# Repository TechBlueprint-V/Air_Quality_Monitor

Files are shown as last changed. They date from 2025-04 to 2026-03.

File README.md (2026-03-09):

# Air_Quality_Monitor

This is an open-source, modular air quality monitoring system designed for both urban and remote deployments. It uses a combination of ESP32 and STM32 microcontrollers to collect and process real-time environmental data from various sensors measuring PM2.5, PM10, CO₂, VOCs, O₃, SO₂, and NO₂. The system features LoRa communication for long-range data transmission, GPS for location tagging, and a solar panel and charger for long-term usage. The hardware is custom-designed and includes power management for battery operation, while the firmware is optimized for low-power performance. All PCB designs, firmware code, and 3D-printed enclosure files are provided in this repository.

# Block Diagram

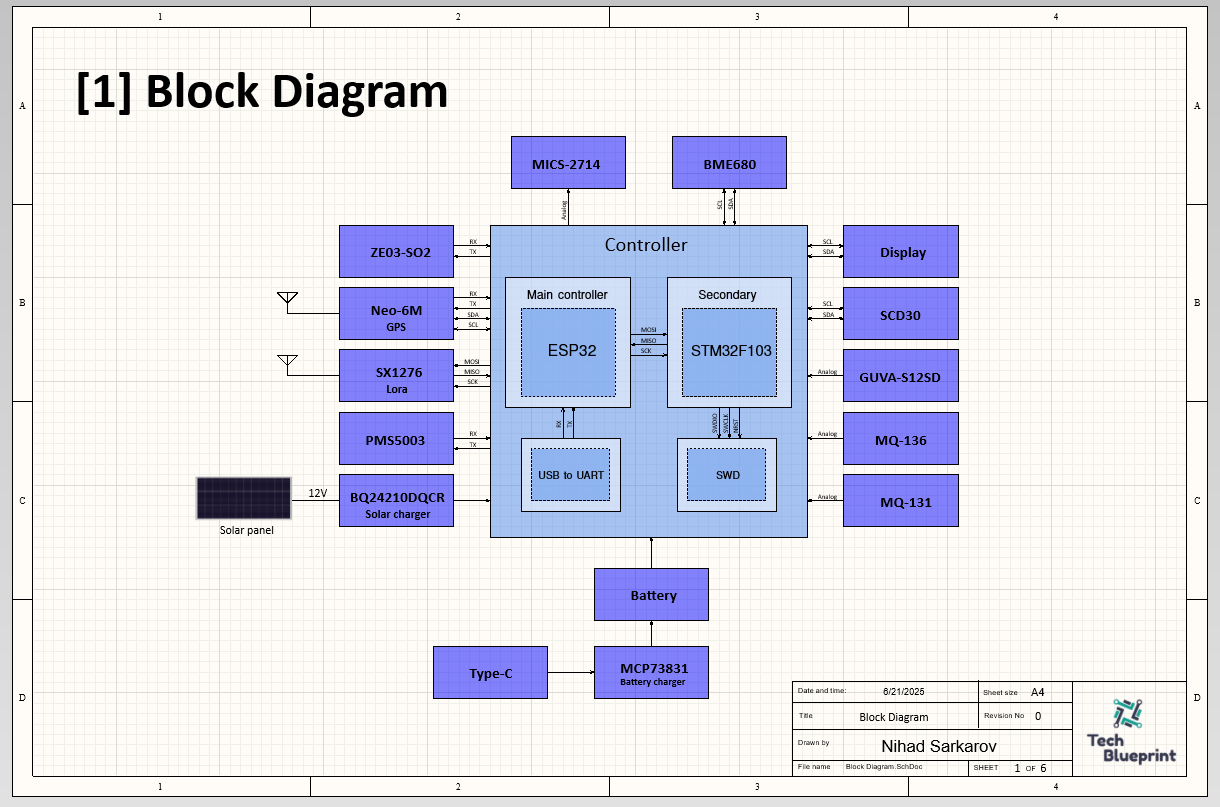
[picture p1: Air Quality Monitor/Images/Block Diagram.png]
Block Diagram


## Real View

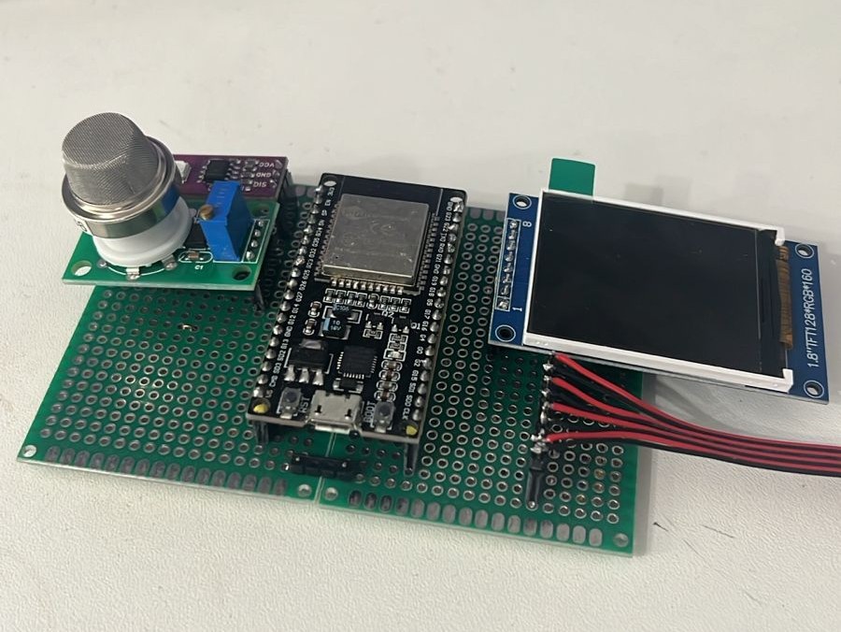
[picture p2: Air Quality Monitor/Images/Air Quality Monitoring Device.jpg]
Real View


*Note: The device shown above is an early prototype and not the final version. Development is still ongoing, and once the fully assembled version is complete, updated images and design details will be added here.* 

# Contents
- [Used Tools](#Used-Tools)
- [Features and Specifications](#Features-and-Specifications)
- [Schematic](#Schematic)
- [Layout](#Layout)
- [3D Views](#3D-Views)
- [Enclosure](#Enclosure)
- [Future Work](#Future-Work)
- [References](#References)

## Used Tools

**Altium Designer**

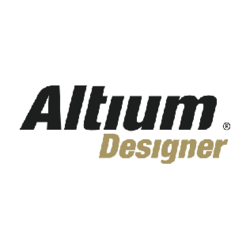
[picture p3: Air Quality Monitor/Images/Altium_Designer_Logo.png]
Altium Logo


   - Altium Designer (AD) is a software package for printed circuit board (PCB) design and electronic design automation. It is developed by the American software company Altium Limited. Altium Designer was formerly known under the brand Protel.

  **Saturn PCB Toolkit**

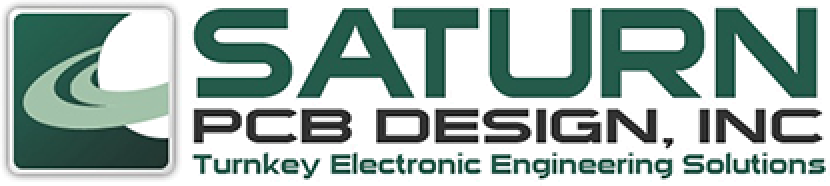
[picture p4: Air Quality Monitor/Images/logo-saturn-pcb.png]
Saturn PCB Toolkit Logo


  - The Saturn PCB Toolkit is the best freeware resource for PCB-related calculations. It incorporates many features that PCB designers and engineers regularly need, like the current capacity of a PCB trace, via current, differential pairs, and much more.

  **SolidWorks**

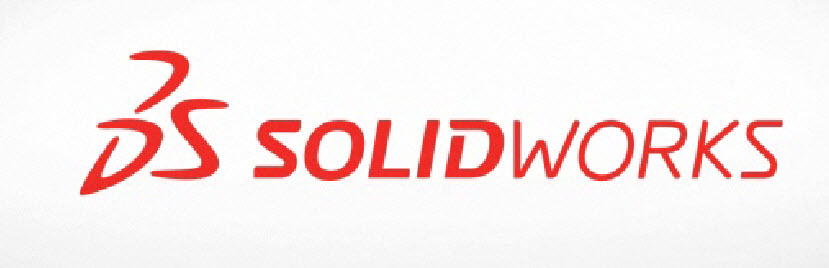
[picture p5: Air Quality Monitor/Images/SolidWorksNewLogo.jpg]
SolidWorks Logo


  - SolidWorks (stylized as SOLIDWORKS ) is a computer-aided 3D solid modeling and design (3D CAD) software. SolidWorks Corporation was founded in 1993 by Jon Hirschtick in Concord, Massachusetts. It was acquired by Dassault Systèmes in 1997 after releasing the first version of the software in 1995. It was the first 3D solid modeling (3D CAD) software integrated into Windows.

## Features and Specifications

| Feature | Description |
|---|---|
| Microcontrollers | ESP32 and STM32F103C8T6 (dual MCU architecture for efficient task handling)|
| Particulate Matter Sensor | PMS5003 - Measures PM2.5 and PM10 |
| Gas Sensors | MQ-136 (SO₂), MQ-131 (O₃), MICS-2714 (NO₂), BME680 (VOC) |
| CO₂ Sensor | SCD30 - Measures CO₂, humidity, and temperature |
| UV Sensor | GUVA-S12SD - Detects UV light intensity |
| Environmental Sensor | BME680 - Measures temperature, pressure, humidity, VOC |
| Communication | LoRa SX1276 - 868 MHz long-range wireless data transmission |
| GPS Module | NEO-6M - Provides geolocation tagging |
| Display | 1.54-inch TFT LCD - Displays live sensor readings |
| Power Supply | 1100mAh Li-ion Battery + USB-C charging |
| Power Management | MCP73831, MP2182GTL-Z, MIC2250, BQ24210 for voltage regulation and charging |
| Enclosure | 3D-printed custom case for outdoor use |
| Use Case Examples | Urban pollution monitoring, smart agriculture, remote environmental sensing |

## Schematic

**MCU**

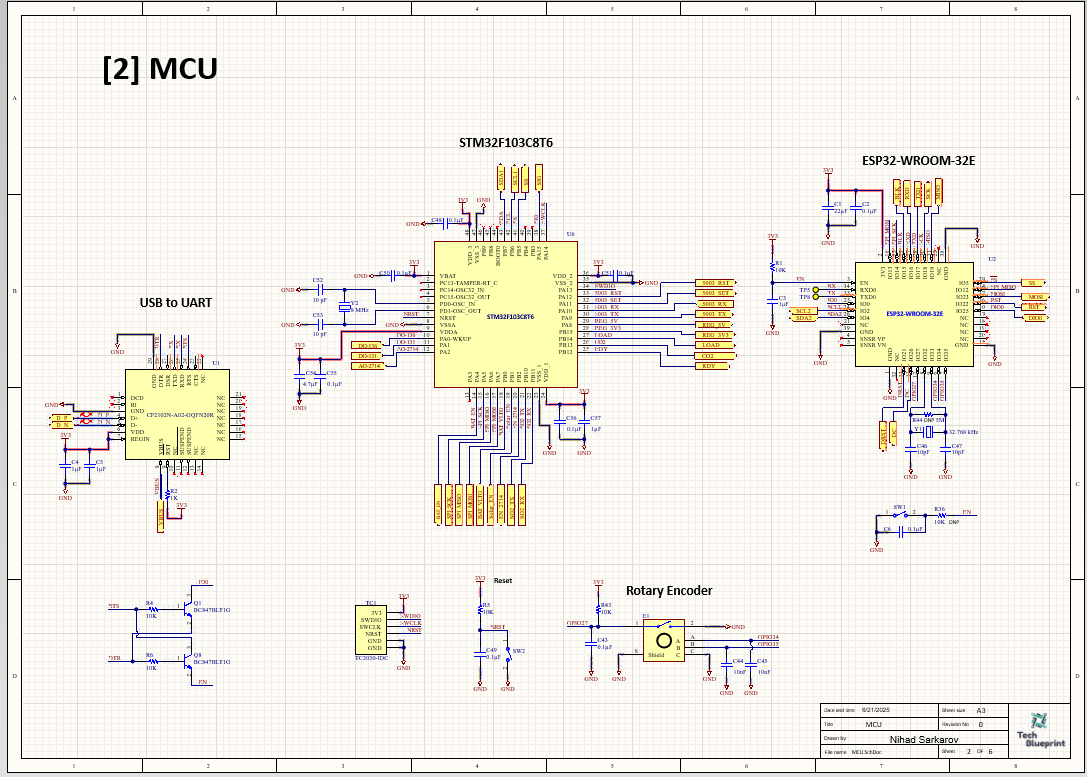
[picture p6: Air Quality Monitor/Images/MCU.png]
MCU


**Sensors**

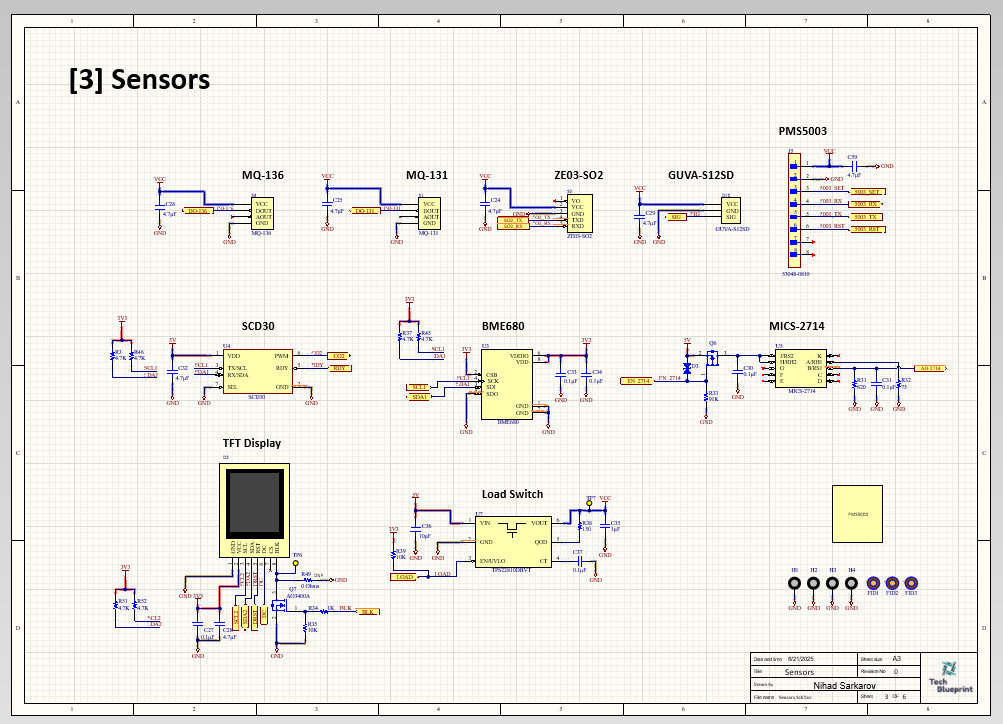
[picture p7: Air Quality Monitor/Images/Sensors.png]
Sensors


**Lora**

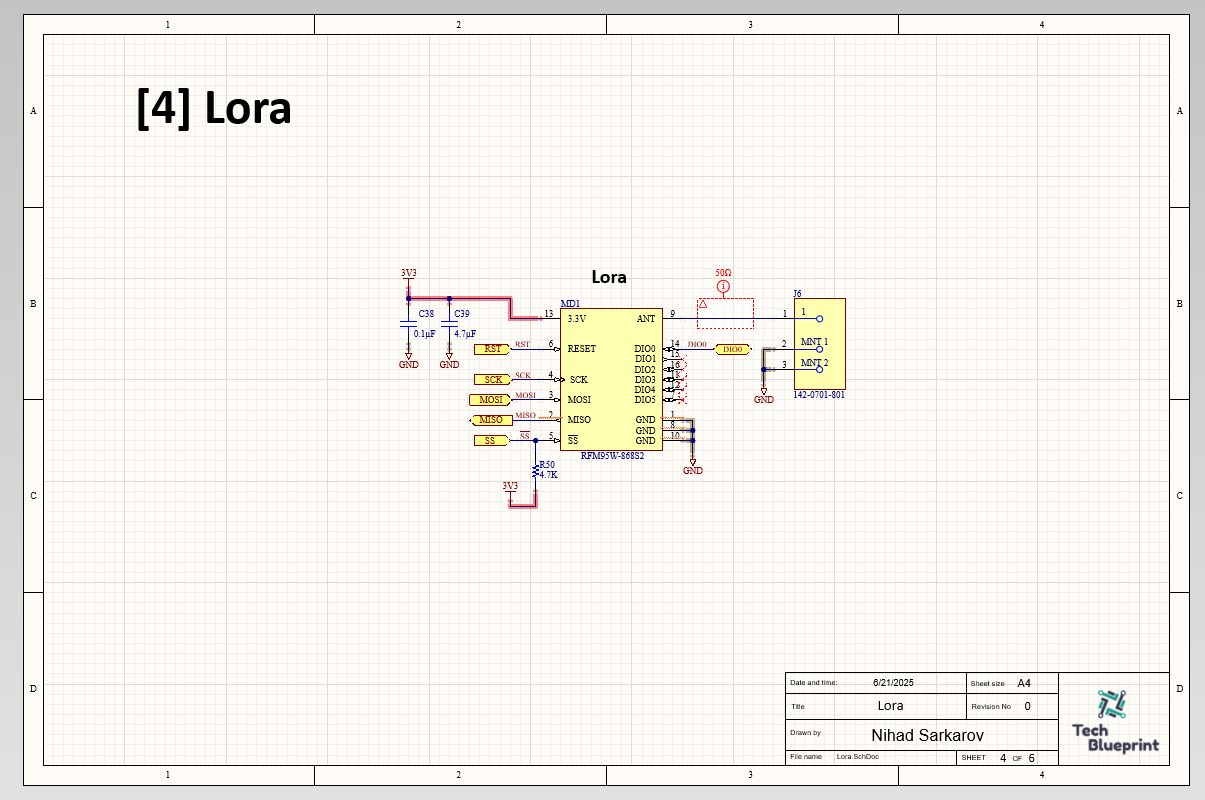
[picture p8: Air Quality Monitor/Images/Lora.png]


**GPS**

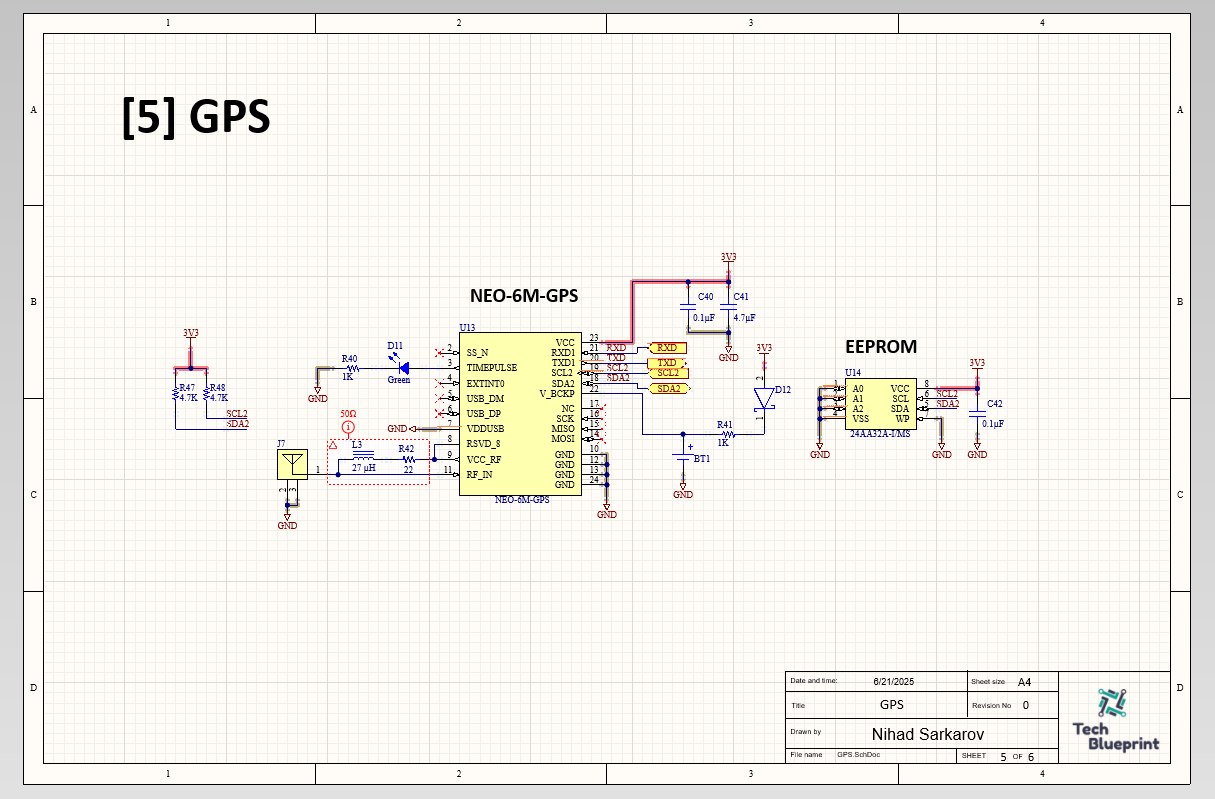
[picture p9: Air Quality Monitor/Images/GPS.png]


**Power**

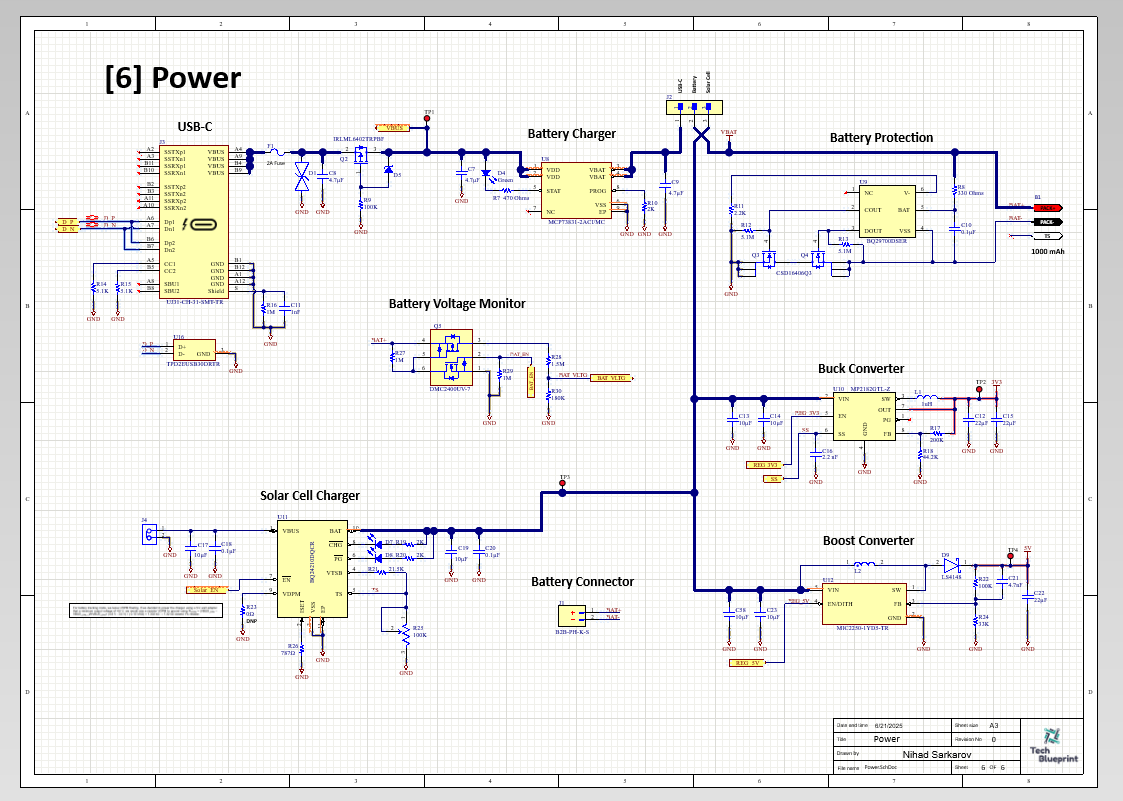
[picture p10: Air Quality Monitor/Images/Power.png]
Power


## Layout

**Layer-1**

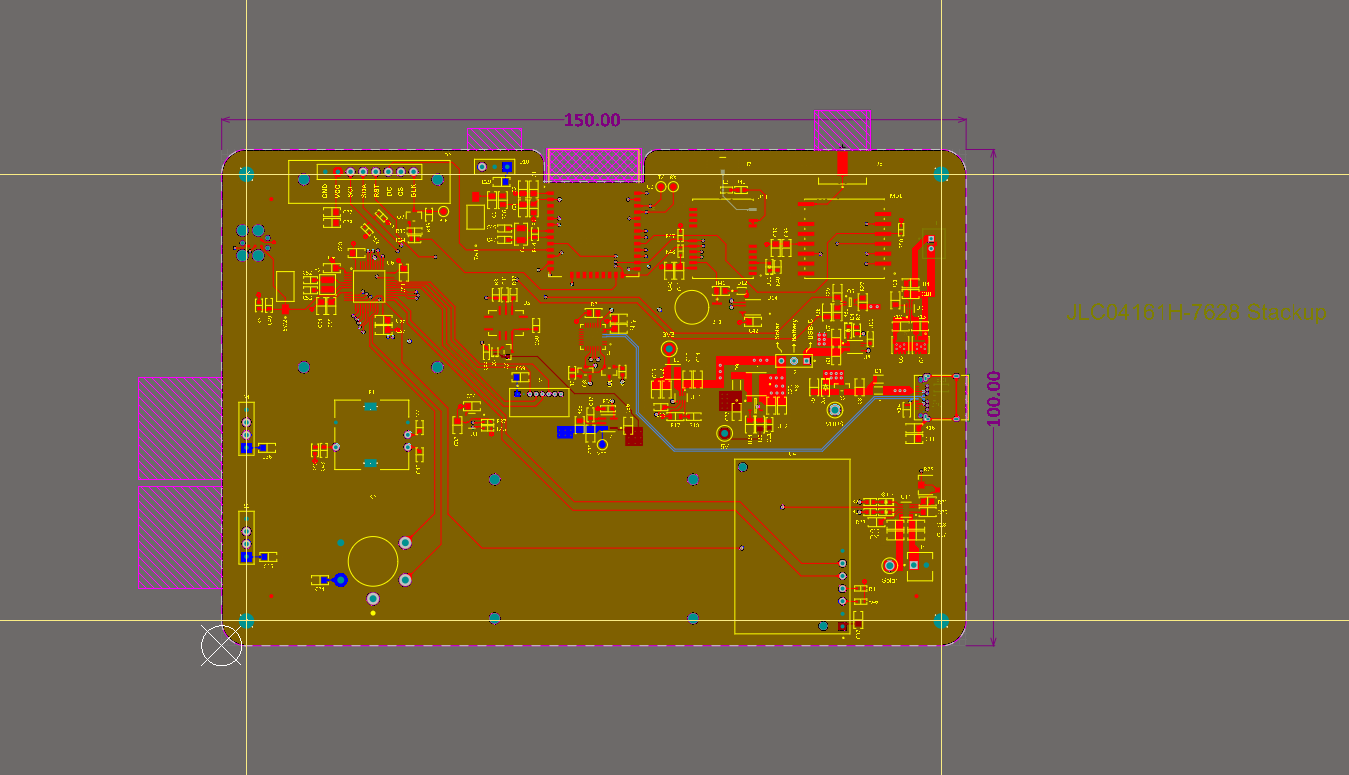
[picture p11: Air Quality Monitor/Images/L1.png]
Layer-1


**Layer-2**

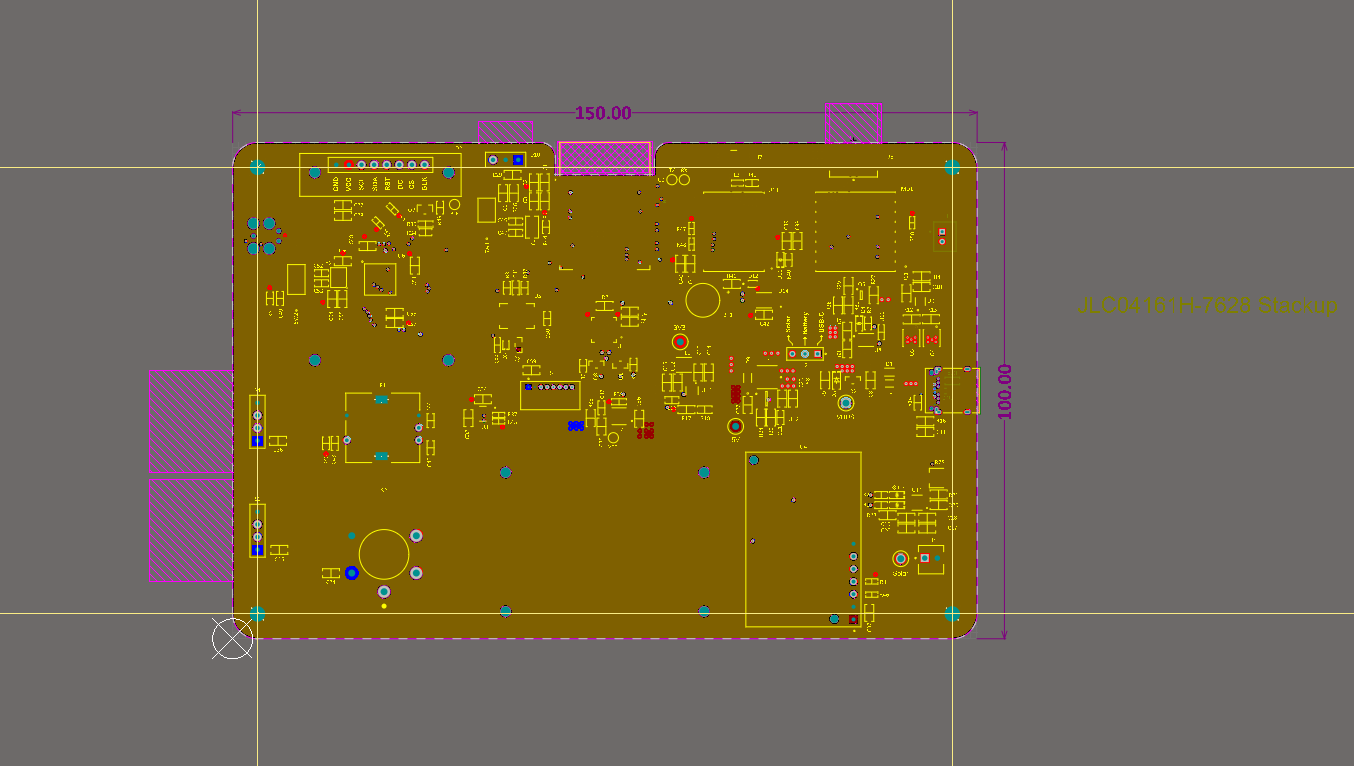
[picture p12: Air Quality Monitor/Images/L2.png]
Layer-2


**Layer-3**

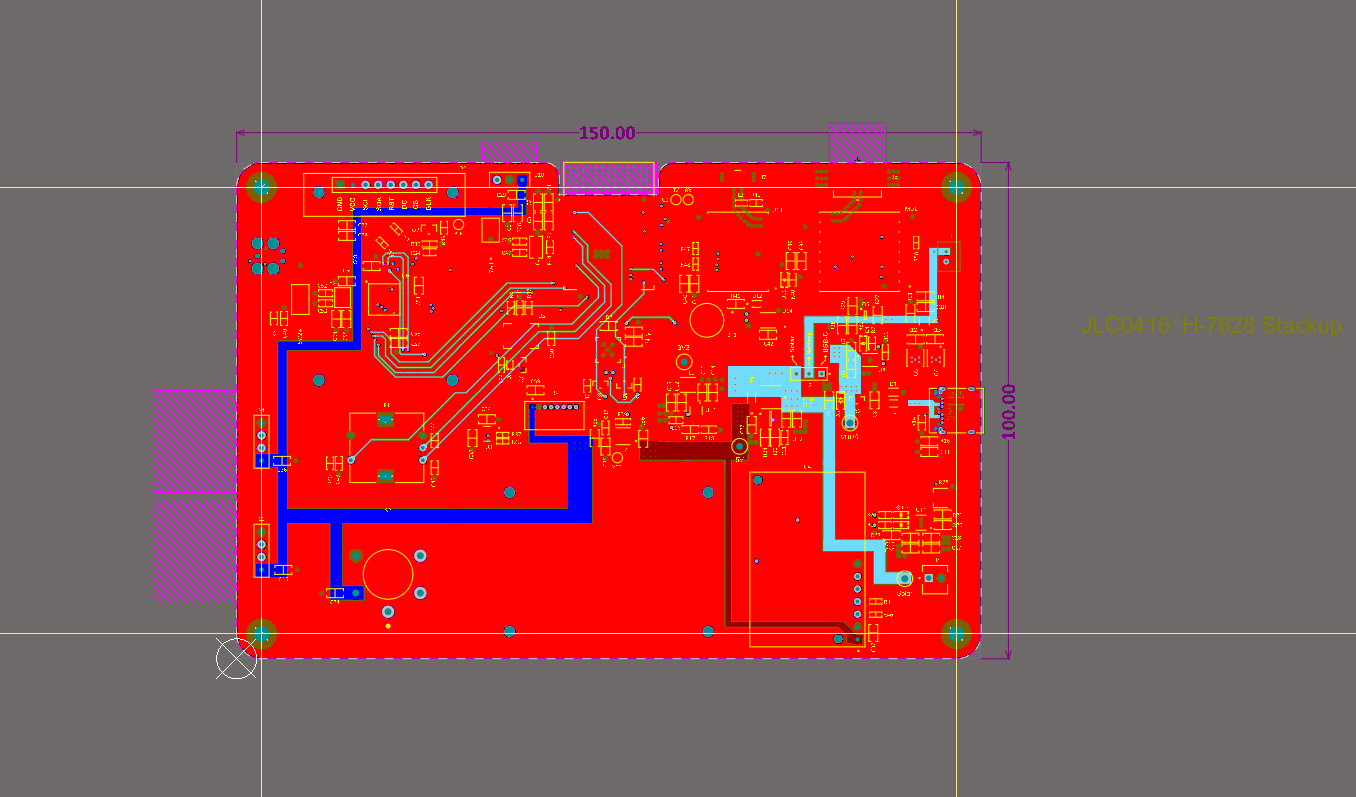
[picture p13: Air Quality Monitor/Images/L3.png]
Layer-3


**Layer-4**

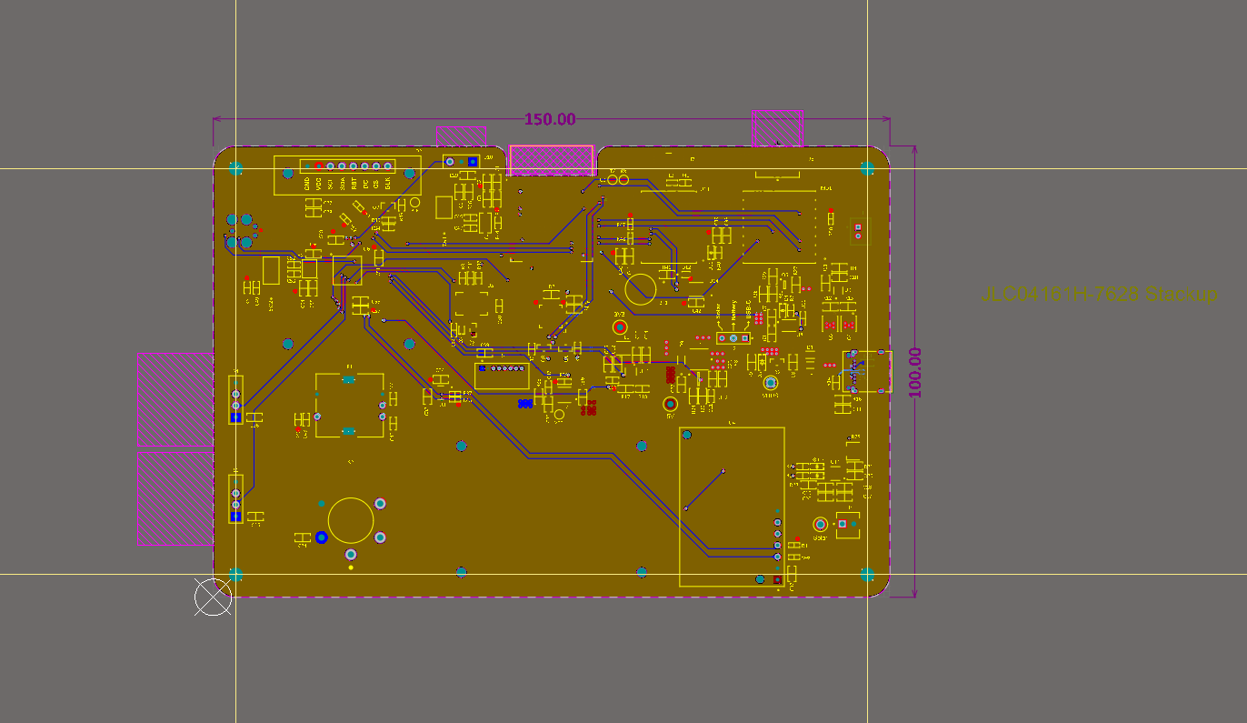
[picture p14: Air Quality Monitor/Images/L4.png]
Layer-4


## 3D Views

**3D-Top**

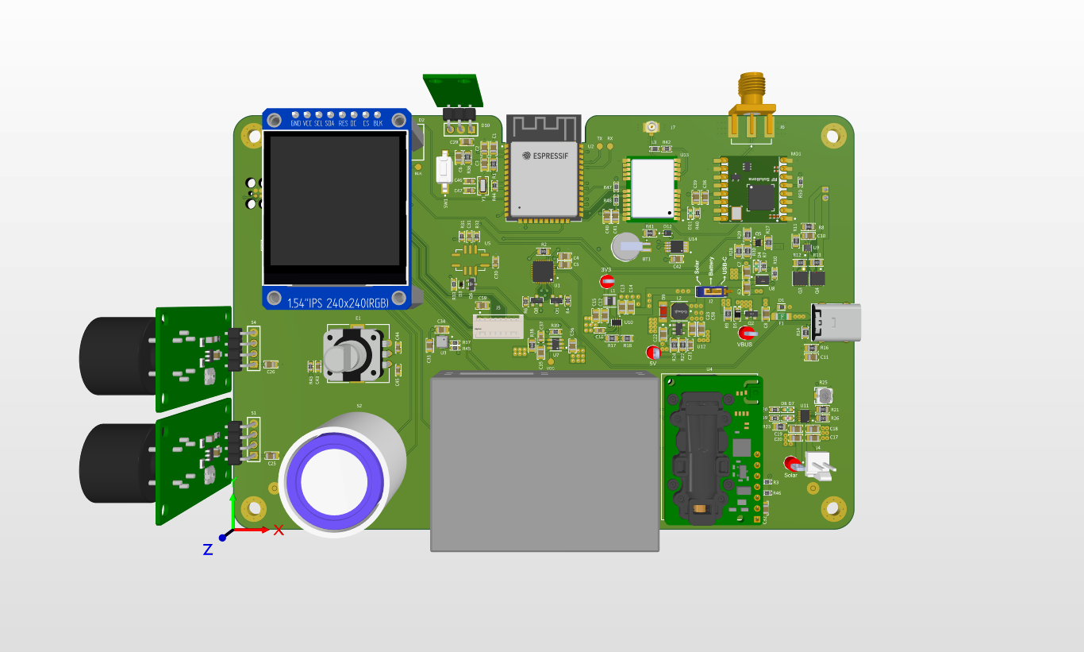
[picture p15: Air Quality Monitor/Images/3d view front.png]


**3D-Bottom**

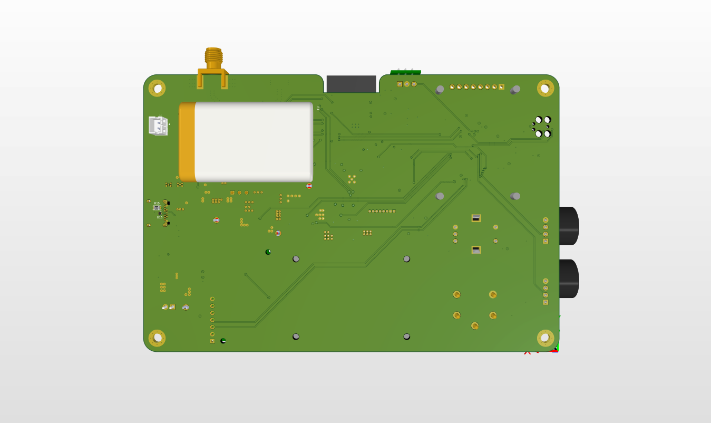
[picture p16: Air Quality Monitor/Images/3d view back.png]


**3D-Profile**

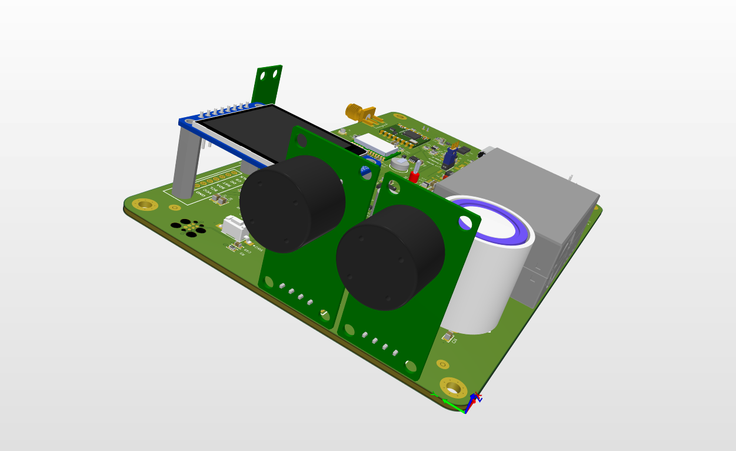
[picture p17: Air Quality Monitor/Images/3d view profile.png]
3D Profile


## Enclosure

**Enclosure view 1**

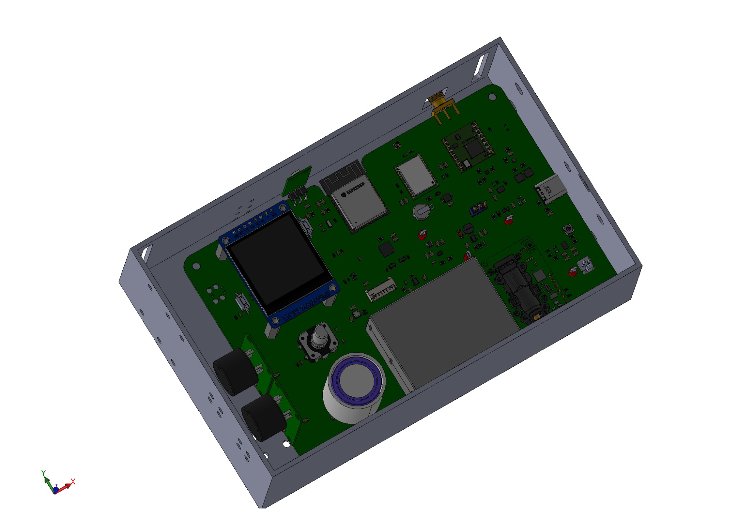
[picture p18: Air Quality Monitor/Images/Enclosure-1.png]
Enclosure-1


**Enclosure view 2**

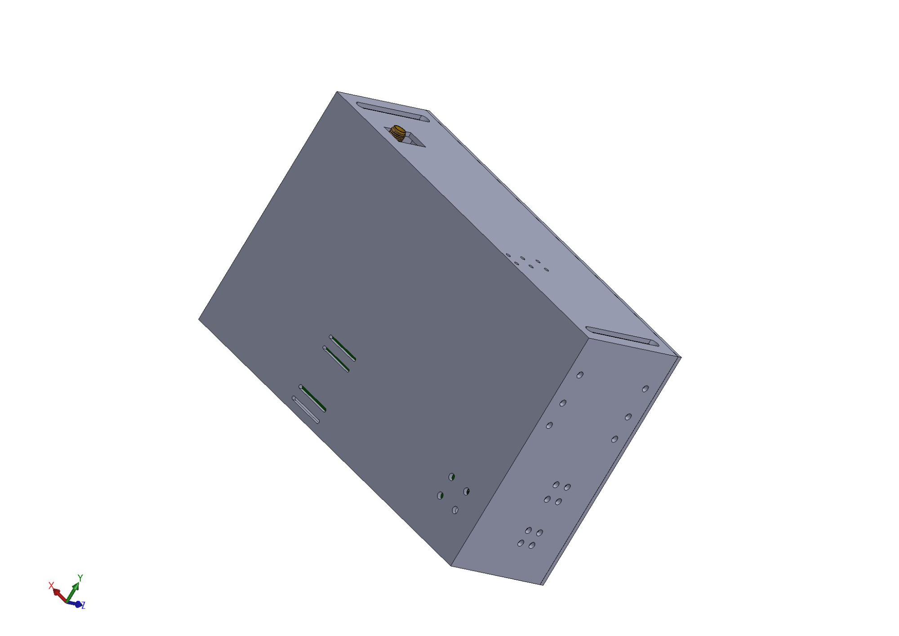
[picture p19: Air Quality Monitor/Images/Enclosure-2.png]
Enclosure-2


**Enclosure view 3**

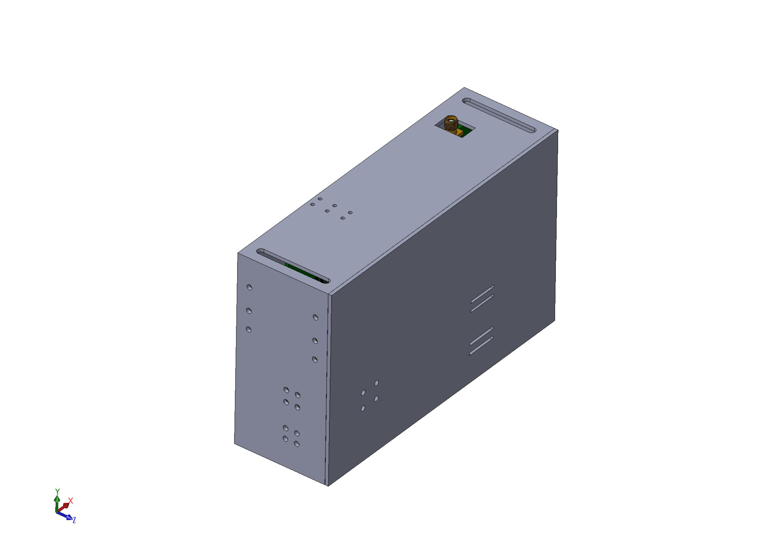
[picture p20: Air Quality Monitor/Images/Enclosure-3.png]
Enclosure-3


**Enclosure view 4**

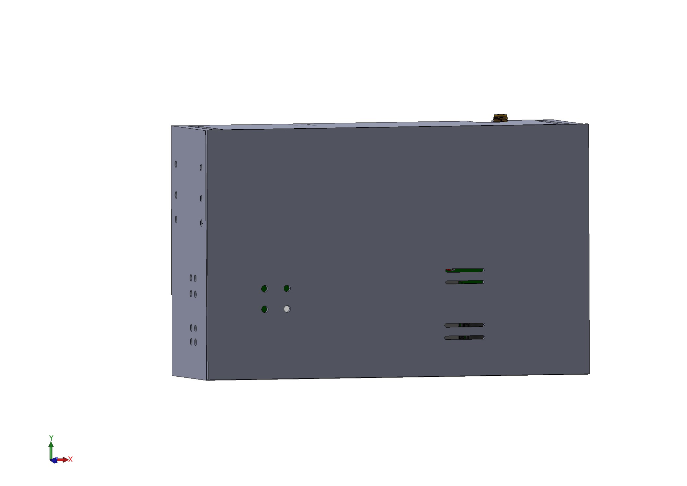
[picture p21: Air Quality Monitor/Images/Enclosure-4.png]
Enclosure-4


**Enclosure view 5**

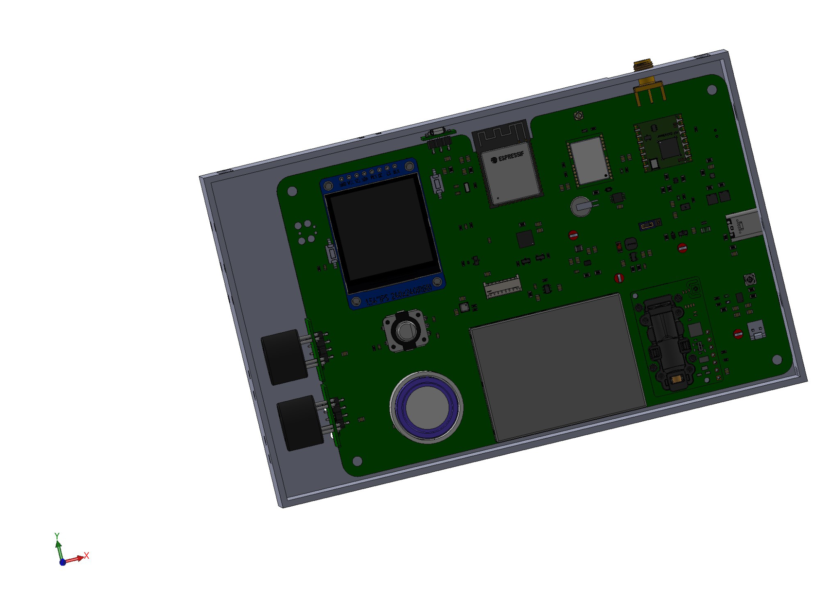
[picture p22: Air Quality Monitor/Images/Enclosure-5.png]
Enclosure-5


## Future Works

- **Cloud Integration and Dashboard**: Develop a cloud-based data logging and visualization dashboard to store historical air quality data and present trends using interactive charts and maps.
- **Mobile Application**: Create a companion Android/iOS app for real-time monitoring, GPS-based pollution alerts, and historical data access.
- **OTA (Over-the-Air) Firmware Updates**: Implement OTA functionality for ESP32 to allow remote firmware upgrades without physical access.
- **Machine Learning for Pollution Prediction**: Integrate lightweight ML models to analyze collected data and predict air quality trends based on environmental factors.
- **Solar Power Option**: Design and test a solar-powered charging module to support long-term outdoor deployment without manual charging.
- **Additional Sensors**: Expand sensor support for detecting carbon monoxide (CO), lead (Pb), or other industrial pollutants.
- **LoRaWAN Gateway Support**: Enable compatibility with public or private LoRaWAN gateways to support broader communication networks.

## Contributors

- **Nihad Sarkarov** – Hardware architecture, PCB design, component selection -   [LinkedIn](https://www.linkedin.com/in/nihad-sarkarov-35b959232/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)

- **Farid Murshudlu** – Firmware development, application UI design -  [LinkedIn](https://www.linkedin.com/in/farid-murshudlu/)
 
- **Ali Askerov** – Mechanical design, enclosure design -  [LinkedIn](https://www.linkedin.com/in/ali-askarov-596a0b258/)
  
## References

1. Plantower PMS5003 Datasheet – [https://files.particle.io](https://www.aqmd.gov/docs/default-source/aq-spec/resources-page/plantower-pms5003-manual_v2-3.pdf)
2. Sensirion SCD30 CO2 Sensor Datasheet – [https://www.sensirion.com](https://sensirion.com/media/documents/4EAF6AF8/61652C3C/Sensirion_CO2_Sensors_SCD30_Datasheet.pdf)
3. Bosch BME680 Sensor Datasheet – [https://www.bosch-sensortec.com](https://www.bosch-sensortec.com/media/boschsensortec/downloads/datasheets/bst-bme680-ds001.pdf)
4. MQ Sensor Series Overview – [https://www.winsen-sensor.com](https://www.pololu.com/file/0j309/mq2.pdf)
5. NEO-6M GPS Module Datasheet – [https://cdn.sparkfun.com](https://content.u-blox.com/sites/default/files/products/documents/NEO-6_DataSheet_%28GPS.G6-HW-09005%29.pdf)
6. Semtech SX1276 LoRa Transceiver Datasheet – [https://www.semtech.com](https://semtech.my.salesforce.com/sfc/p/E0000000JelG/a/2R0000001Rbr/6EfVZUorrpoKFfvaF_Fkpgp5kzjiNyiAbqcpqh9qSjE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)
7. STM32F103C8T6 Reference Manual – [https://www.st.com]([https://www.st.com/resource/en/reference_manual/CD00171190.pdf](https://www.st.com/resource/en/reference_manual/rm0008-stm32f101xx-stm32f102xx-stm32f103xx-stm32f105xx-and-stm32f107xx-advanced-armbased-32bit-mcus-stmicroelectronic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))
8. ESP32 Technical Reference Manual – [https://www.espressif.com](https://www.espressif.com/sites/default/files/documentation/esp32_technical_reference_manual_en.pdf)
9. [PlatformIO](https://platformio.org/) – Cross-platform development environment
10. [STM32CubeIDE](https://www.st.com/en/development-tools/stm32cubeide.html) – Integrated development tool for STM32 microcontrollers

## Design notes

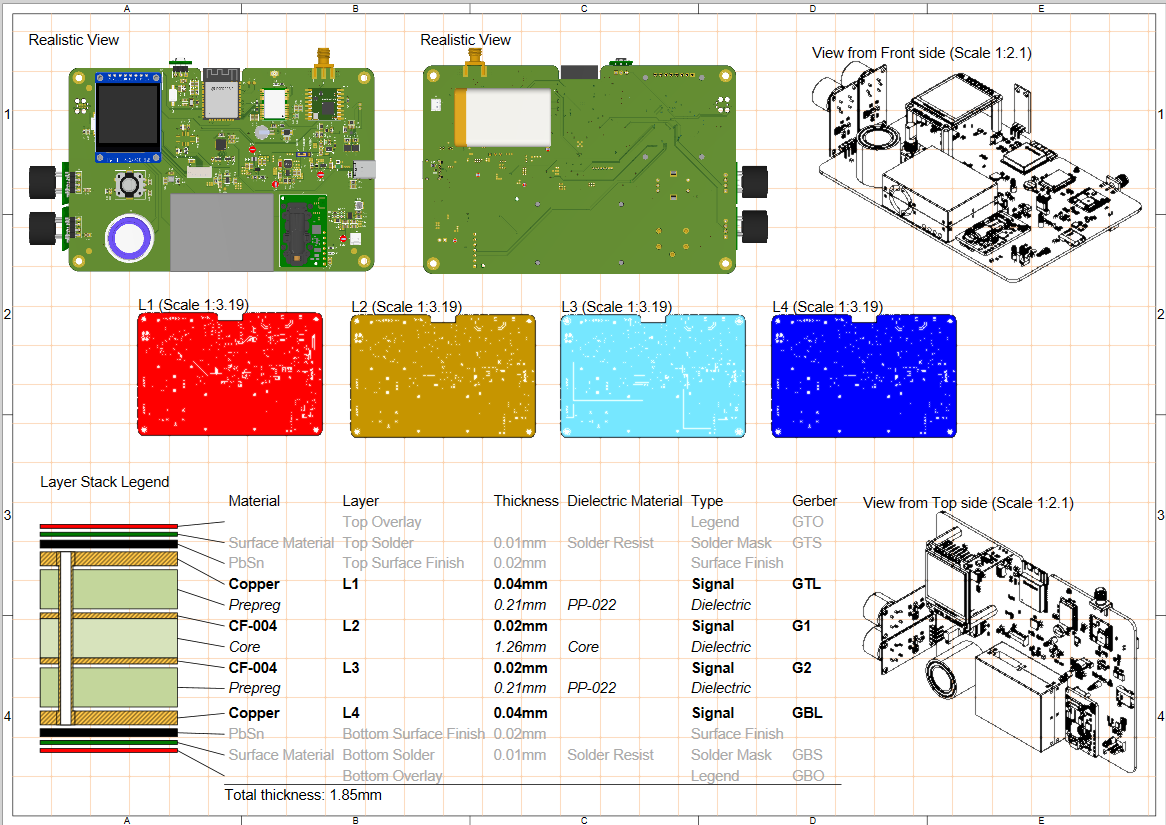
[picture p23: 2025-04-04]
Air Quality Monitor/Hardware Design Files/Altium/Draftsman/Draftsman.png

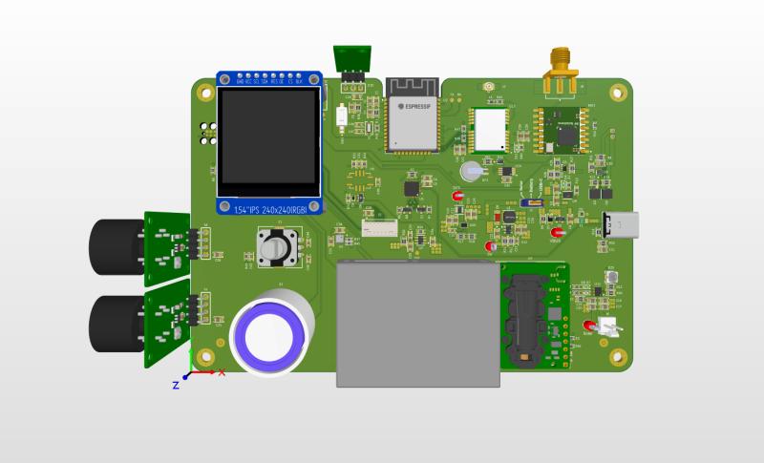
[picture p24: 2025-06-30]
Air Quality Monitor/Images/3D Top.jpeg

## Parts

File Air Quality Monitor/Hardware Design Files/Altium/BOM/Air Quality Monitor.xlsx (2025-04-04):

Comment | Description | Designator | Footprint | LibRef | Quantity
Battery | 1000 mAh | B1 | 1000 mAh battery | Battery | 1
MS621FE-FL11E |  | BT1 | BAT_MS621FE-FL11E | MS621FE-FL11E | 1
22µF | CAP CER 22UF 6.3V X5R 0805 | C1, C12, C15, C22 | CAP 0805_2012 | 08056D226KAT2A | 4
0.1µF | CAP CER 0.1UF 25V X7R 0805 | C2, C6, C10, C18, C20, C27, C33, C34, C38, C40, C42, C48, C50, C51, C55, C56 | CAP 0805_2012 | 08053C104KAT4A, 08053C104K4Z2A | 16
1µF | CAP CER 1UF 6.3V X5R 0805, CAP CER 1UF 10V X7R 0805 | C3, C4, C5, C35, C57 | CAP 0805_2012 | LGC26D105MAT2S1, MM05ZC105KCZ2A | 5
4.7µF | CAP CER 4.7UF 10V X5R 0805 | C7, C8, C9, C24, C25, C26, C28, C29, C32, C39, C41, C54, C59 | CAP 0805_2012 | 0805ZD475KAT2A | 13
1000 pF | CAP CER 0805 1NF 250V C0G 1% | C11 | CAP 0805_2012 | C0805C102FAGECAUTO | 1
10µF | CAP CER 10UF 10V X5R 0805 | C13, C14, C17, C19, C23, C36, C58 | CAP 0805_2012 | 0805ZD106KAT4A | 7
2200 pF | CAP CER 0603 2.2NF 16V X7R 10% | C16 | CAP 0603_1608 | C0603C222K4RECAUTO | 1
4700 pF | CAP CER 0603 4.7NF 16V X7R 10% | C21 | CAP 0603_1608 | C0603C472K4RECAUTO | 1
0.1µF | CAP CER 0.1UF 16V X7R 0603, CAP CER 0.1UF 25V X7R 0603 | C30, C31, C37, C43, C49 | CAP 0603_1608 | 0603YC104KAT4A, 06033C104K4T4A | 5
10000 pF | CAP CER 0603 10NF 16V X7R 10% | C44, C45 | CAP 0603_1608 | C0603C103K4RECAUTO | 2
10pF | CAP CER 10PF 50V NP0 0603 | C46, C47 | CAP 0603_1608 | 06035A100J4T2A | 2
10 pF | CAP CER 10PF 50V C0G/NP0 0603 | C52, C53 | CAP 0603_1608 | 500X14N100MV4T | 2
EZA-EG3A50AV | EZA-EG3A50AV EZAEG Series 100 Vcl 0.1 pF 0603 Surface Mount ESD Suppressor | D1 | FP-EZAEG3A-MFG | CMP-00287-39618349-1 | 1
1.54 Inch TFT | 1.54 inch TFT Display 1.54" LCD Screen Module 240*240 240x240 SPI interface ST7789 Driver Board | D2 | 1.54 Inch Display | Display | 1
RCLAMP2261PW.C | 22V ESD & EOS PROTECTION | D3 | 0402 | RCLAMP2261PW.C | 1
Green | LED GREEN CLEAR CHIP 0603 SMD | D4, D8, D11 | LED 0603_1608 GREEN | LSM0603453V | 3
PZU3.0B2A,115 | DIODE ZENER 3V 320MW SOD323 | D5 | SOD323 | PZU3.0B2A,115 | 1
Red | 0603 LED RED 620NM DOMINANT,630N | D7 | LED 0603_1608 RED | QBLP601-R5-2897 | 1
LS4148 | DIODE GEN PURP 75V 150MA SOD80 | D9 | FP-6_560-5006_01-4-MFG | CMP-02539-000014-1 | 1
GUVA-S12SD | Photodiode 2-SMD, J-Lead | D10 | GUVA-S12SD | GUVA-S12SD | 1
B0530WS-7-F | DIODE SCHOTTKY 30V 500MA SOD323 | D12 | FP-SOD323-MFG | CMP-12790-000023-1 | 1
PEC11R-4315F-S0012 | ROTARY ENCODER MECHANICAL 12PPR | E1 | BOURNS PEC11R-4315F-S0012 | PEC11R-4315F-S0012 | 1
3413.0219.22 | FUSE BRD MNT 2A 32VAC 63VDC 1206 | F1 | FUSE 1206_3216 0.6MM | 3413.0219.22 | 1
Mounting Hole |  | H1, H2, H3, H4 | Mounting Hole | Mounting Hole | 4
B2B-PH-K-S |  | J1 | JST_B2B-PH-K-S | B2B-PH-K-S | 1
87224-3 | CONN HEADER VERT 3POS 2.54MM | J2 | FP-87224-3-MFG | CMP-2000-05697-2 | 1
UJ31-CH-31-SMT-TR | CONN RCPT USB3.1 TYPEC 24POS R/A | J3 | CUI UJ31-CH-31-SMT-TR | UJ31-CH-31-SMT-TR | 1
640456-2 | Male Header, Pitch 2.54 mm, 1 x 2 Position, Height 10.49 mm, Tail Length 3.556 mm, -55 to 105 degC, RoHS, Bulk | J4 | TECO-640456-2_V | CMP-2000-05417-1 | 1
53048-0810 | CONN HEADER R/A 8POS 1.25MM | J5 | FP-530480810-MFG | CMP-04776-000035-2 | 1
142-0701-801 | CONN SMA JACK STR 50OHM EDGE MNT | J6 | FP-142-0701-801-MFG | CMP-09588-000002-1 | 1
U.FL-R-SMT-1(10) | CONN U.FL RCPT STR 50 OHM SMD | J7 | FP-U_FL-R-SMT-1_10-MFG | CMP-2000-05152-3 | 1
1239AS-H-1R0M=P2 | Shielded Wirewound Inductor 1uH 20% 3000mA 0.059Ω 1008 (2520) | L1 | FP-DFE252012C-IPC_C | CMP-06042-014115-1 | 1
LPS4018-104MRB | INDUCTOR, SHLD, 100UH, 20%, 0.35A, SMD | L2 | FP-LPS4018-MFG | CMP-11268-000169-1 | 1
27 µH | FIXED IND 27UH 2MA 1.8 OHM SMD | L3 | TDK MLF1608 | MLF1608C270KTD00 | 1
RFM95W-868S2 | RX TXRX MODULE ISM < 1GHZ SMD | MD1 | FP-RFM95W-868S2-MFG | CMP-204316-000001-1 | 1
BC847BLT1G |  | Q1, Q8 | ON_Semi_318-08_MFG | CMP-1048-00759-2 | 2
IRLML6402TRPBF | MOSFET P-CH 20V 3.7A SOT-23 | Q2 | FP-Micro3-MFG | CMP-32901-000130-1 | 1
CSD16406Q3 | MOSFET N-CH 25V 60A 8-SON | Q3, Q4 | FP-DQG0008A-MFG | CMP-04962-000044-1 | 2
DMC2400UV-7 | Complementary Pair Enhancement Mode MOSFET, 20 V N-Channel, -20 V P-Channel, -55 to 150 degC, 6-Pin SOTFL (SOT563), RoHS, Tape and Reel | Q5 | DIOD-SOT563-6_V | CMP-2000-06168-1 | 1
SI2301BDS-T1-GE3 | SI2301BDS-T1-GE3 Trans Mosfet P-ch Si 20V 2.2A 3-PIN SOT-23 T/r / Mosfet P-ch 20V 2.2A SOT23-3 | Q6 | FP-S-03946-MFG | CMP-00030-42864886-1 | 1
AO3400A | MOSFET N-CH 30V 5.7A SOT23 | Q7 | FP-SOT23-MFG | CMP-83955-000006-1 | 1
10K | RES SMD 10K OHM 5% 1/3W 0805 | R1, R36 | RES 0805_2012 | CRGH0805J10K | 2
1K | RES SMD 1K OHM 5% 1/3W 0805 | R2, R41 | RES 0805_2012 | CRGH0805J1K0 | 2
4.7K | RES 4.7K OHM 5% 1/10W 0603 | R3, R37, R45, R46, R47, R48, R50, R51, R52 | KOA RES RK73 RN73 0603_1608 | RK73B1JTTD472J | 9
10K | RES SMD 10K OHM 5% 1/10W 0603 | R4, R5, R6, R43 | RES 0603_1608 | CRCW060310K0JNEA | 4
470 Ohms | RES 470 OHM 5% 1/10W 0603 | R7 | RES 0603_1608 | RMCF0603JT470R | 1
330 Ohms | RES 330 OHM 5% 1/8W 0805 | R8 | RES 0805_2012 | CRCW0805330RJNEAC | 1
100K | RES 100K OHM 1% 1/3W 0805 | R9, R22 | RES 0805_2012 | CRGP0805F100K | 2
2K | RES 2K OHM 1% 1/10W 0603 | R10 | YAGEO RES 0603_1608 | RC0603FR-072KP | 1
2.2K | RCC0805 100 2K2 1% ET1 E3 | R11 | RES 0805_2012 | RCC08052K20FKEA | 1
5.1M | RES SMD 5.1M OHM 5% 0.4W 0805 | R12, R13 | RES 0805_2012 | ESR10EZPJ515 | 2
5.1K | RES 5.1K OHM 5% 1/4W 0805 | R14, R15 | YAGEO RES RK73 RS73 SG73 0805_2012 | SG73S2ATTD512J | 2
1M | RES SMD 1M OHM 1% 1/2W 0805, RES SMD 1M OHM 5% 1/2W 0805 | R16, R27, R29 | RES 0805_2012 | RCS08051M00FKEA, CRCW08051M00JNEAHP | 3
200K | RES 200K OHM 1% 1/8W 0805 | R17 | YAGEO RES 0805_2012 | RC0805FR-07200KL | 1
44.2K | RES 44.2K OHM 1% 1/4W 0805 | R18 | YAGEO RES RK73 RS73 SG73 0805_2012 | RK73H2ATTD4422F | 1
2K | RES 2K OHM 5% 1/10W 0603 | R19, R20 | RES 0603_1608 | RMCF0603JT2K00 | 2
21.5K | RCG0805 100 21K5 1% EA | R21 | RES 0805_2012 | RCG080521K5FKEA | 1
0Ω | RES SMD 0 OHM 1% 1/8W 0805 | R23 | RES 0805_2012 | CRCW0805787RFKEA | 1
33K | RES 33K OHM 1% 1/3W 0805 | R24 | RES 0805_2012 | CRGP0805F33K | 1
TC33X-2-104E | TRIMMER 100K OHM 0.1W J LEAD TOP | R25 | FP-TC33X-2-MFG | CMP-07234-000040-1 | 1
787Ω | RES SMD 787 OHM 1% 1/8W 0805 | R26 | RES 0805_2012 | CRCW0805787RFKEA | 1
1.5M | RES 1.5M OHM 1% 1/8W 0805 | R28 | RES 0805_2012 | RMCF0805FT1M50 | 1
180K | RES 180K OHM 1% 1/3W 0805 | R30 | RES 0805_2012 | CRGP0805F180K | 1
820 | RES SMD 820 OHM 1% 1/10W 0603 | R31 | RES 0603_1608 | KTR03EZPF8200 | 1
75 | RES SMD 75 OHM 1% 1/10W 0603 | R32 | RES 0603_1608 | RCA060375R0FKEA | 1
91K | RES 91K OHM 5% 1/10W 0603 | R33 | YAGEO RES 0603_1608 | RC0603JR-0791KL | 1
1K | RES 1K OHM 5% 1/10W 0603 | R34, R40 | RES 0603_1608 | RMCF0603JT1K00 | 2
10K | RES SMD 10K OHM 5% 1/10W 0603 | R35, R39 | YAGEO RES 0603_1608 | AC0603JR-0710KL | 2
150 | RES 150 OHM 1% 1/3W 0805 | R38 | RES 0805_2012 | CRGP0805F150R | 1
22 | RES SMD 22 OHM 1% 1/10W 0603 | R42 | RES 0603_1608 | ERJ-3EKF22R0V | 1
5M | RES SMD 5M OHM 1% 1/10W 0603 | R44 | RES 0603_1608 | HVC0603T5004FET | 1
0 Ohms | RES 0 OHM JUMPER 0603 | R49 | RES 0603_1608 | TLRZ1JTTD | 1
MQ-131 | MQ-131 Sensor Module | S1 | MQ-131 Sensor Module | MQ-131 Module | 1
ZE03-SO2 | Portable and fixed gas detector, various gas detection equipment and situation. | S2 | ZE03-SO2 | ZE03-SO2 | 1
MQ-136 | They are used in air quality control equipments for buildings/offices, are suitable for detecting Of H2S | S4 | MQ-136 Sensor Module | MQ-136 Sensor Module | 1
FSMSMTR | FSMSM Push Button Switch, 50 mA, -35 to 85 degC, 2-Pin SMD, RoHS, Tape and Reel | SW1, SW2 | TECO-FSMSMTR_V | CMP-2000-07501-1 | 2
TC2030-IDC | PLUG-OF-NAILS 6-PIN W/ LEGS 8 | TC1 | TC2030-IDC | TC2030-IDC | 1
5010 | Test Point, Red, Through Hole, RoHS, Bulk | TP1, TP2, TP3, TP4 | KSTN-5010_V | CMP-1672-00002-4 | 4
Test point | 1mm x 1mm round pad for testing purposes | TP5, TP6, TP7, TP8 | Test point | Test point | 4
CP2102N-A02-GQFN20R | USB Bridge, USB to UART USB 2.0 UART Interface 20-QFN (3x3) | U1 | QFN50P500X500X100-29N | CP2102 | 1
ESP32-WROOM-32E(M113EH3200PH3Q0) | RX TXRX MOD WIFI TRACE ANT SMD | U2 | FP-ESP32-WROOM-32E_M113EH-MFG | CMP-194065-000012-1 | 1
BME680 |  | U3 | PSON80P300X300X100-8N | BME680 | 1
SCD30 | CO2 MODULE | U4 | FP-SCD30-MFG | CMP-144026-000005-1 | 1
MICS-2714 | Gas sensor for Nitrogen Dioxide | U5 | MICS-SMD10 | MICS-2714 | 1
STM32F103C8T6 | ARM® Cortex®-M3 STM32F1 Microcontroller IC 32-Bit 72MHz 64KB (64K x 8) FLASH 48-LQFP (7x7) | U6 | LQFP-48_19.6_393_58X11_SMD | IC_STM32F103C8T6 | 1
TPS22810DBVT | IC PWR SWITCH N-CHAN 1:1 SOT23-6 | U7 | FP-DBV0006A-IPC_A | CMP-04912-000018-2 | 1
MCP73831-2ACI/MC | IC CONTROLLER LI-ION 4.2V 8DFN | U8 | FP-C04-123-MFG | CMP-06318-000002-1 | 1
BQ29700DSER | IC LITHIUM BATT PROTECT 6-SON | U9 | FP-DSE0006A-IPC_A | CMP-04911-000043-1 | 1
MP2182GTL-Z | Buck Switching Regulator IC Positive Adjustable 0.6V 1 Output 2A SOT-583 | U10 | SOT583_MP2182_MNP | MP2182GTL-Z | 1
BQ24210DQCR |  | U11 | SON50P300X200X80-11N | BQ24210DQCR | 1
MIC2250-1YD5-TR | IC REG BOOST ADJ 900MA SOT23-5 | U12 | FP-MIC2250-1YD5-TR-IPC_C | CMP-06325-000043-1 | 1
NEO-6M-GPS |  | U13 | XCVR_NEO-6M-GPS | NEO-6M-GPS | 1
24AA32A-I/MS |  | U14 | SOP65P490X110-8N | 24AA32A-I/MS | 1
PMS5003 | https://www.digikey.jp/htmldatasheets/production/2903006/0/0/1/pms5003-series-manual.html | U15 | PMS5003 | PMS5003 | 1
TPD2EUSB30DRTR | ESD Solution for Super-Speed (6 Gbps) USB 3.0 Interface, 2 Channels, -40 to +85 degC, 3-pin SOT (DRT), Green (Rohs & No Sb/Br) | U16 | DRT0003A | CMP-0326-00046-3 | 1
32.768 kHz | CRYSTAL 32.7680KHZ 7PF SMD | Y1 | ABRACON ABS07 | ABS07-32.768KHZ-7-T | 1
8 MHz | CRYSTAL 8.0000MHZ 8PF SMD | Y2 | NDK NX3225GD | CG04874-8M | 1

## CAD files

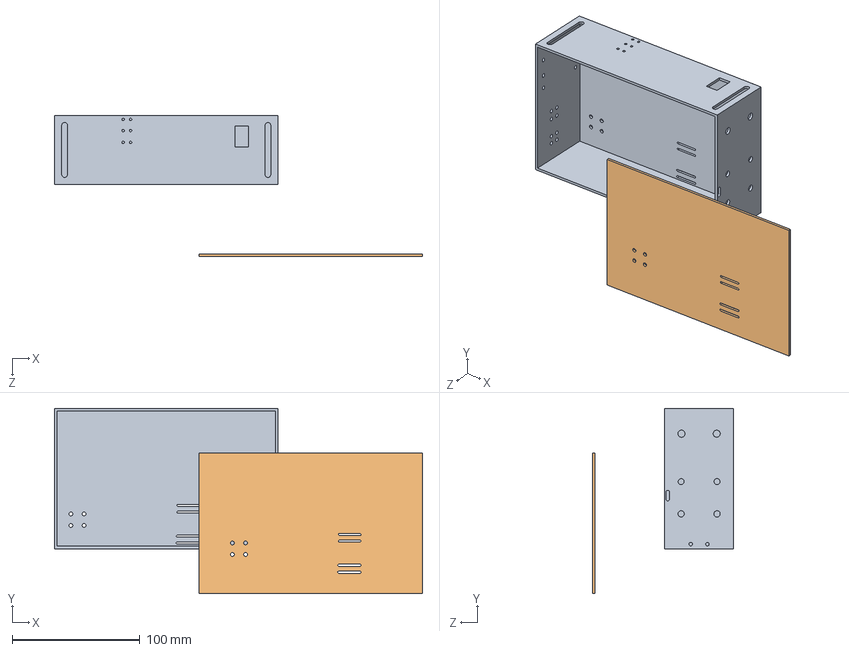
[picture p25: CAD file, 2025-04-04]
Air Quality Monitor/Mechanical Design Files/STEP/PCB Box.STEP
288.1 x 145.2 x 110.5 mm
Cover project
cover qapaq
